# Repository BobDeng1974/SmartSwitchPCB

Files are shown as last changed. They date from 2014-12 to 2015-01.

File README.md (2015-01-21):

SmartSwitchPCB
==============

Eagle and Gerber Files for the PCB of the [SmartSwitch](https://github.com/phhe/spark_smartswitch) with the Spark Core.

## Layout 
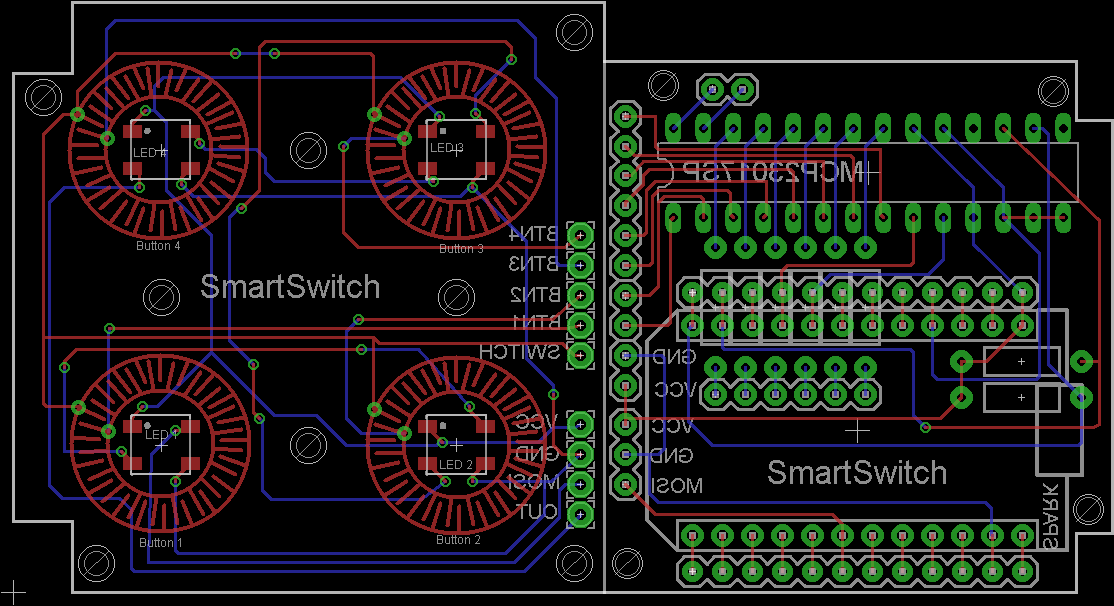
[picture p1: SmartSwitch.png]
Board Layout


### Check Layout
1. Open brd-Layout
2. Tools -> DRC
3. Load
4. Choose 'ITEADstudio_DRC.dru' (ftp://imall.iteadstudio.com/PCBs/ITEADstudio_DRC.zip)
5. Check... 

### Generate Gerbers
1. Open brd-Layout
2. File -> CAM Processor
3. File -> Open --> Job ...
4. Choose 'ITeadstudio_CAM6.cam'  (ftp://imall.iteadstudio.com/PCBs/ITEADstudio_CAM%20for%20Eagle6.x.zip)
5. Execute Job...

## Case

The SmartSwitch Case is for the ButtonPad version of the SmartSwitch.
It is based on a Layout from [MakerCase](http://makercase.com) and the  [Arduinome eXperimenter’s Case](http://interactives.artsrn.ualberta.ca/?page_id=133).

The *.eps file can be ordered at [ponoko.com](http://ponoko.com) or [formulor.de](http://formulor.de)

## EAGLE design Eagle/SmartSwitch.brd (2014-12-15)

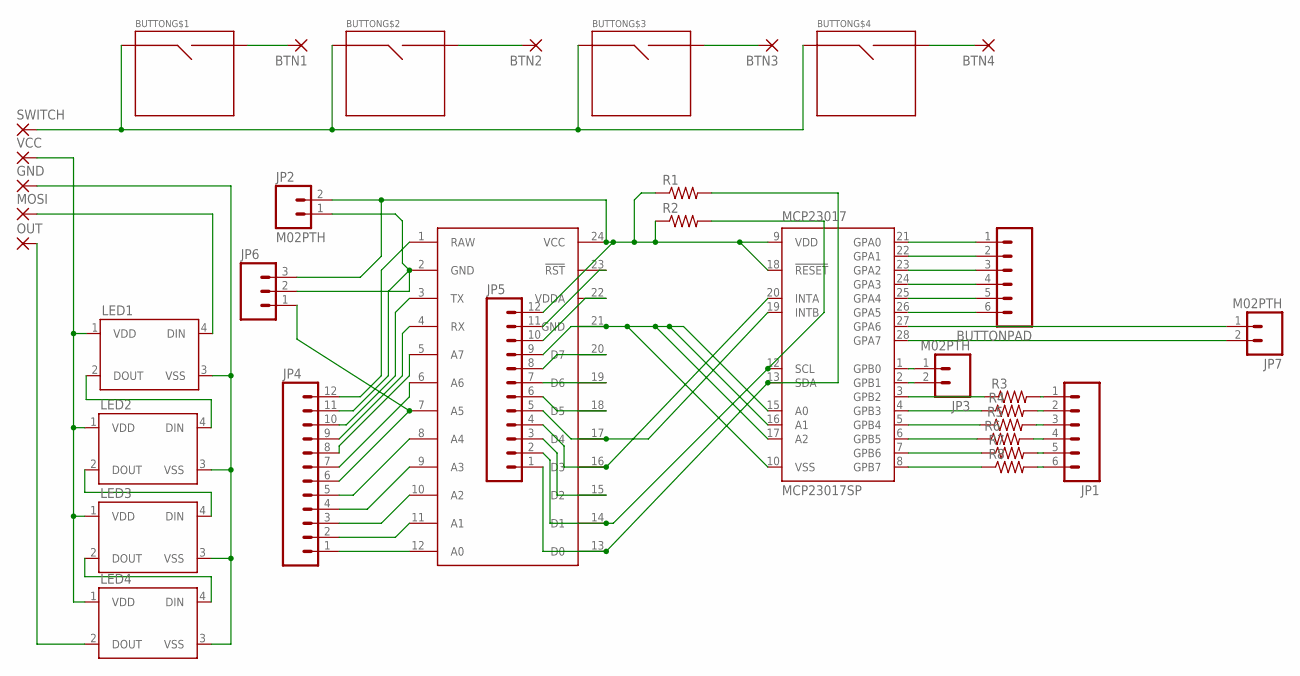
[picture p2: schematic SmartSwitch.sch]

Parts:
BTN1, BTN2, BTN3, BTN4: 2,15/1,0
BUTTON: BUTTON
BUTTONPAD: M06SILK_FEMALE_PTH; 1X06
GND: 2,15/1,0
JP1: M06SILK_FEMALE_PTH; 1X06
JP2, JP3, JP7: M02PTH; 1X02
JP4, JP5: M12PTH; 1X12-SMALL-PADS
JP6: M03PTH; 1X03
LED1, LED2, LED3, LED4: WS2812B
MCP23017: MCP23017SP; DIL28-3
MOSI: 2,15/1,0
OUT: 2,15/1,0
R1, R2, R3, R4, R5, R6, R7, R8: RESISTORPTH-1/4W; AXIAL-0.4
SPARK: SPARK_CORECORE; SPARK_CORE
SWITCH: 2,15/1,0
VCC: 2,15/1,0

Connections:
GROUND: GND.1, LED1.3 (VSS), LED2.3 (VSS), LED3.3 (VSS), LED4.3 (VSS)
MOSI: LED1.4 (DIN), MOSI.1
unnamed: BTN1.1, BUTTON.SIG2
unnamed: BTN2.1, BUTTON.SIG4 (SIG2)
unnamed: BTN3.1, BUTTON.SIG6 (SIG2)
unnamed: BTN4.1, BUTTON.SIG8 (SIG2)
unnamed: BUTTONPAD.1, MCP23017.21 (GPA0)
unnamed: BUTTONPAD.2, MCP23017.22 (GPA1)
unnamed: BUTTONPAD.3, MCP23017.23 (GPA2)
unnamed: BUTTONPAD.4, MCP23017.24 (GPA3)
unnamed: LED4.2 (DOUT), OUT.1
unnamed: LED1.1 (VDD), LED2.1 (VDD), LED3.1 (VDD), LED4.1 (VDD), VCC.1
unnamed: LED1.2 (DOUT), LED2.4 (DIN)
unnamed: LED2.2 (DOUT), LED3.4 (DIN)
unnamed: LED3.2 (DOUT), LED4.4 (DIN)
unnamed: BUTTONPAD.5, MCP23017.25 (GPA4)
unnamed: BUTTONPAD.6, MCP23017.26 (GPA5)
unnamed: JP7.1, MCP23017.27 (GPA6)
unnamed: JP7.2, MCP23017.28 (GPA7)
unnamed: JP3.1, MCP23017.1 (GPB0)
unnamed: JP3.2, MCP23017.2 (GPB1)
unnamed: MCP23017.3 (GPB2), R3.P$1 (1)
unnamed: JP1.1, R3.P$2 (2)
unnamed: JP1.2, R4.P$2 (2)
unnamed: JP1.3, R5.P$2 (2)
unnamed: JP1.4, R6.P$2 (2)
unnamed: JP1.5, R7.P$2 (2)
unnamed: JP5.3, SPARK.15 (D2)
unnamed: JP5.5, MCP23017.19 (INTB), SPARK.17 (D4)
unnamed: JP2.2, JP5.12, JP6.3, MCP23017.9 (VDD), MCP23017.18 (!RESET), R1.P$1 (1), R2.P$1 (1), SPARK.24 (VCC)
unnamed: JP4.6, JP6.1, SPARK.7 (A5)
unnamed: JP2.1, JP4.11, JP6.2, SPARK.2 (GND)
unnamed: JP4.1, SPARK.12 (A0)
unnamed: JP5.9, MCP23017.10 (VSS), MCP23017.15 (A0), MCP23017.16 (A1), MCP23017.17 (A2), SPARK.21 (GND)
unnamed: JP5.2, MCP23017.12 (SCL), R2.P$2 (2), SPARK.14 (D1)
unnamed: JP5.1, MCP23017.13 (SDA), R1.P$2 (2), SPARK.13 (D0)
unnamed: JP4.2, SPARK.11 (A1)
unnamed: JP4.3, SPARK.10 (A2)
unnamed: JP4.4, SPARK.9 (A3)
unnamed: JP4.5, SPARK.8 (A4)
unnamed: JP4.7, SPARK.6 (A6)
unnamed: JP4.8, SPARK.5 (A7)
unnamed: JP4.9, SPARK.4 (RX)
unnamed: JP4.10, SPARK.3 (TX)
unnamed: JP5.6, SPARK.18 (D5)
unnamed: JP4.12, SPARK.1 (RAW)
unnamed: JP1.6, R8.P$2 (2)
unnamed: JP5.8, SPARK.20 (D7)
unnamed: JP5.7, SPARK.19 (D6)
unnamed: JP5.10, SPARK.22 (VDDA)
unnamed: JP5.11, SPARK.23 (!RST)
unnamed: BUTTON.SIG1, BUTTON.SIG3 (SIG1), BUTTON.SIG5 (SIG1), BUTTON.SIG7 (SIG1), SWITCH.1
unnamed: JP5.4, MCP23017.20 (INTA), SPARK.16 (D3)
unnamed: MCP23017.8 (GPB7), R8.P$1 (1)
unnamed: MCP23017.7 (GPB6), R7.P$1 (1)
unnamed: MCP23017.6 (GPB5), R6.P$1 (1)
unnamed: MCP23017.5 (GPB4), R5.P$1 (1)
unnamed: MCP23017.4 (GPB3), R4.P$1 (1)

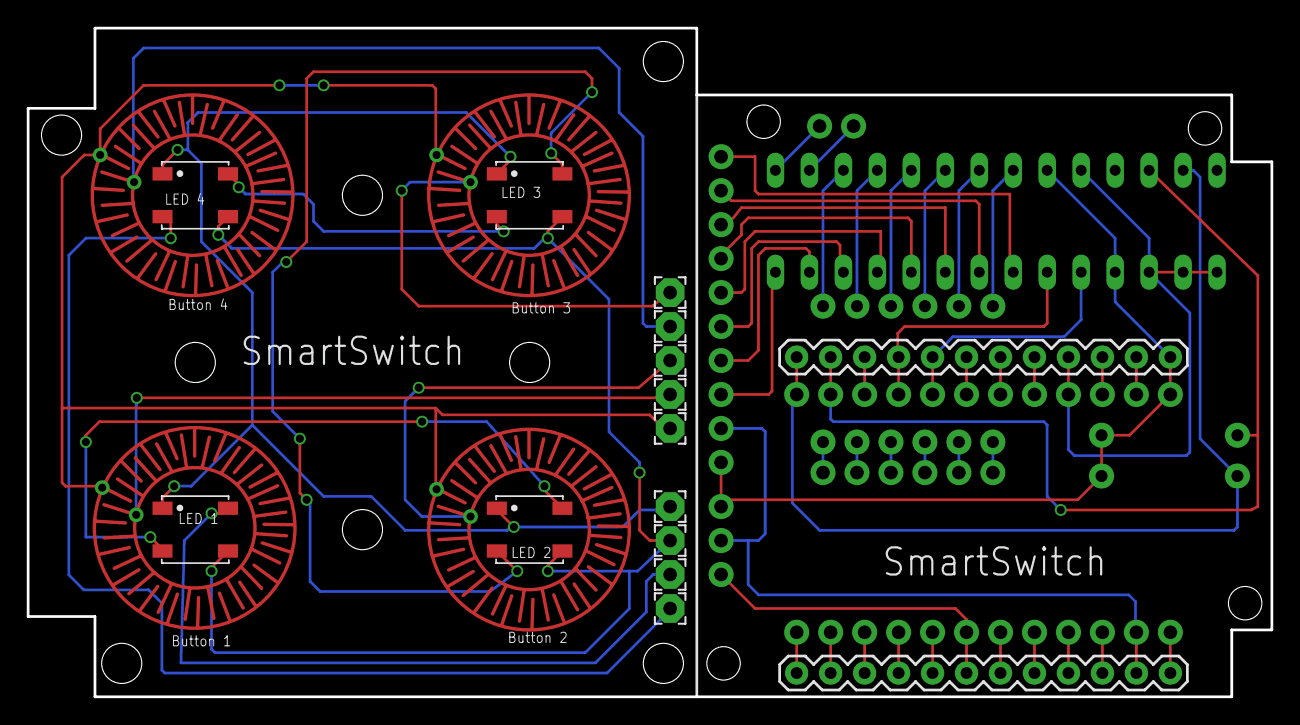
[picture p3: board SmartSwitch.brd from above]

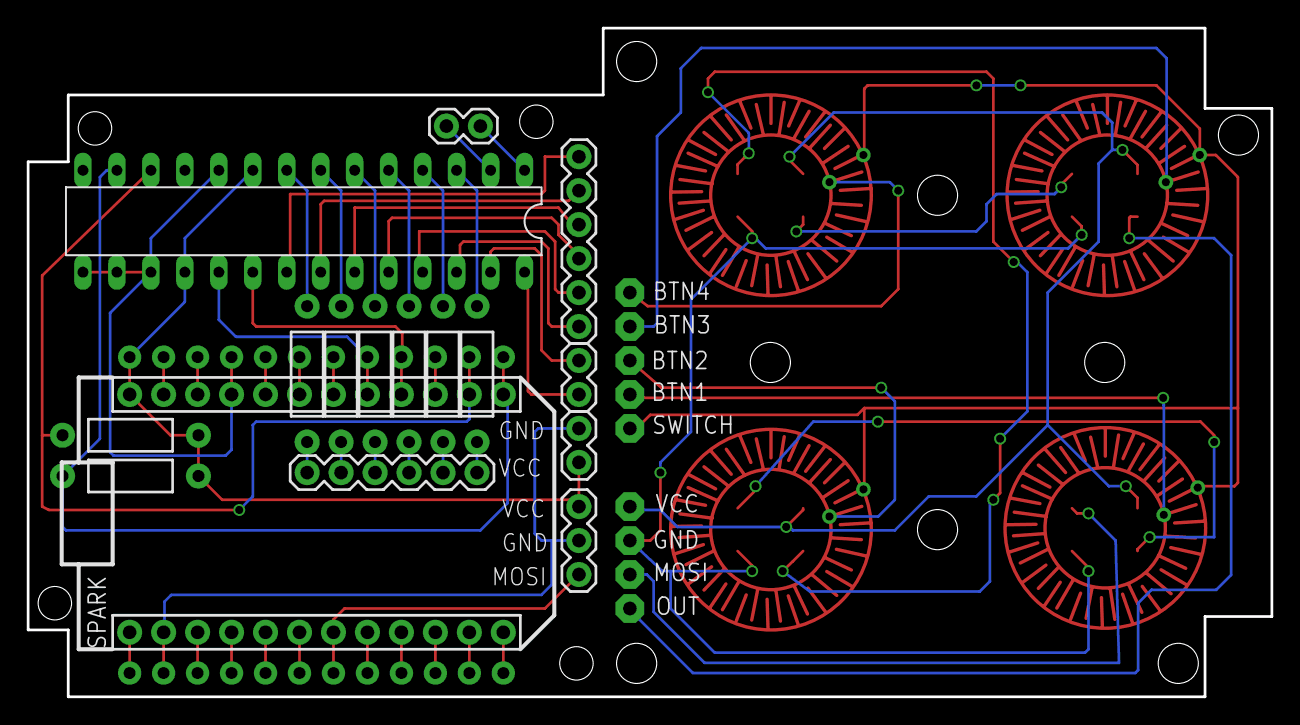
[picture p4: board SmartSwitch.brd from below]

Board: 2 copper layers, 93.0 x 50.0 mm, 32 parts (16 on the bottom side), 58 nets.

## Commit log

2014-12-11 Initial Commit
    Bugfix short-circuit
    [SmartSwitch.brd, SmartSwitch.sch]
2014-12-11 Update WS2812B Positions
    [SmartSwitch.brd]
2014-12-12 Change GND/VCC on Buttonpad connection
    [SmartSwitch.brd]
2014-12-12 Move resistors
    [SmartSwitch.brd, SmartSwitch.sch]
2014-12-15 series resistor, edges
    [SmartSwitch2.brd, SmartSwitch2.sch, SmartSwitch3.brd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]
2014-12-15 Change Jumper
    [SmartSwitch2.brd, SmartSwitch2.sch, SmartSwitch3.brd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]
2015-01-21 Added Case Modell
    [SmartSwitch.GBL, SmartSwitch.GBO, SmartSwitch.GBP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]

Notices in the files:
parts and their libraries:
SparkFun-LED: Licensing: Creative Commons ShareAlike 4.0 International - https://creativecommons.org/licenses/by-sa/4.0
